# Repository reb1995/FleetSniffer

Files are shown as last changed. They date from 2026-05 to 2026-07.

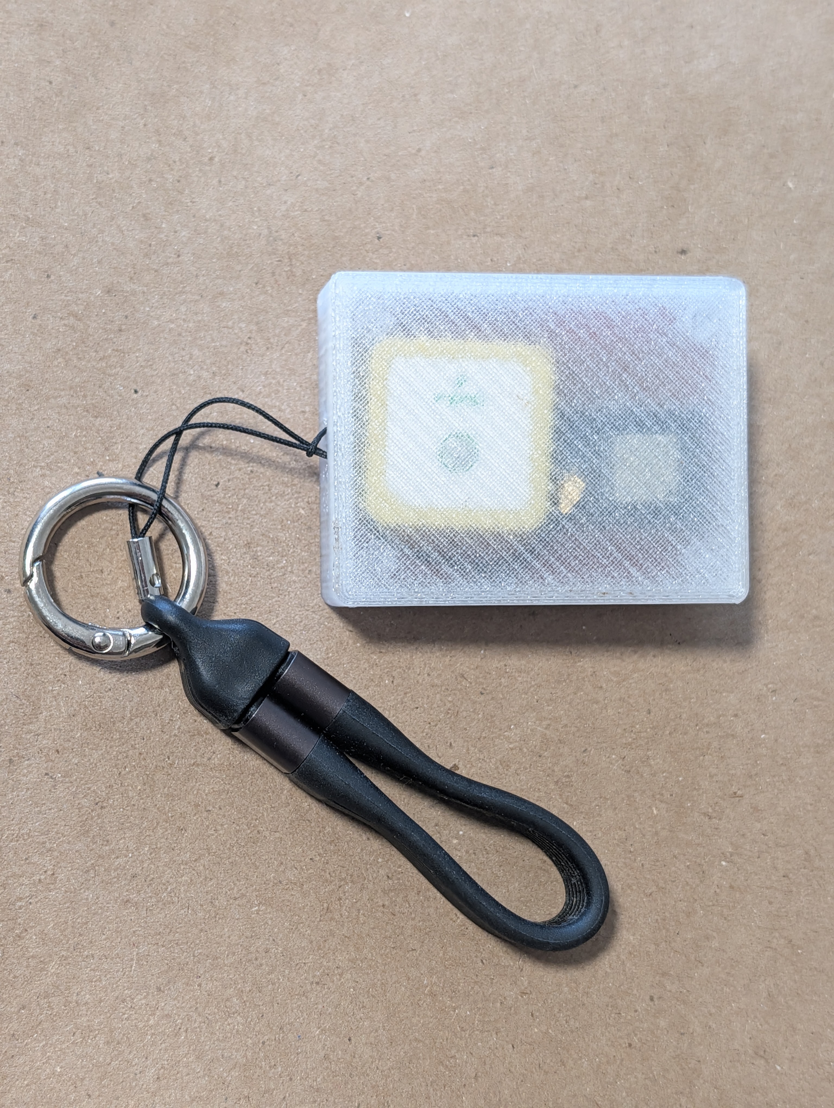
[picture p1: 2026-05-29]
models/images/Bottom.jpg

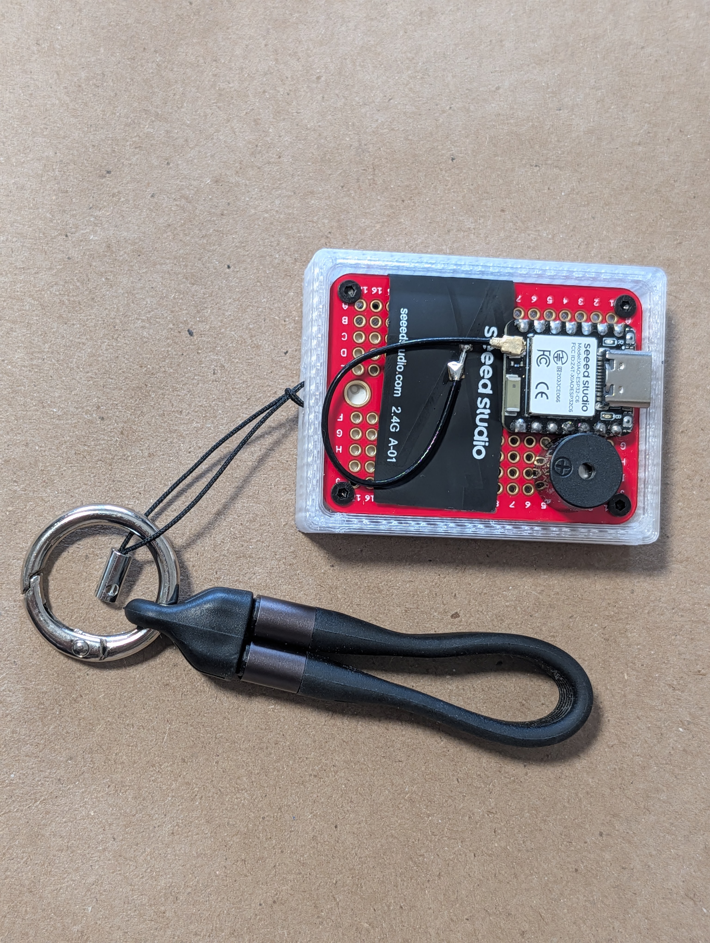
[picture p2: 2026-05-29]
models/images/Top.jpg

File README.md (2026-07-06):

ESP32 Passive Network Monitor
=============================
Pre-Release
------------------
This is a working project, but it is not refined. Some assembly required. For example, the 3d printed case doesn't fit the buzzer and doesn't have a shield to protect the front of the case. Feel free to update and optimize.

Design
------------------

Multi-protocol network monitoring tool built on the ESP-IDF. This firmware passively scans for 802.11 management frames (Beacons, Probe Requests, Probe Responses) and Bluetooth Low Energy (BLE) advertisements. It cross-references captured MAC addresses, OUIs, and SSIDs against embedded watchlists, triggers GPIO alerts upon detection, and logs matched targets to non-volatile SPIFFS memory.

Supported Hardware
------------------

This project leverages static DRAM allocation and IRAM-pinned interrupt callbacks to handle high-density RF environments without dropping packets. It is explicitly designed to compile across multiple ESP32 architectures:

*   **ESP32-C5:** Supports dual-band channel hopping (2.4 GHz & 5 GHz).
    *   Hardware pins:
        *   Buzzer (GPIO 9)
        *   LED (GPIO 27)
*   **ESP32-C6:** High-efficiency 2.4 GHz monitoring.
    *   Hardware pins:
        *   Buzzer (GPIO 20)
        *   LED (GPIO 15)
*   **ESP32-S3:** 2.4 GHz monitoring.
    *   Hardware pins:
        *   Buzzer (GPIO 8)
        *   LED (GPIO 21)

Compile for your specific hardware. The C5 build automatically includes 5 GHz channel sweeping logic.

``` bash
idf.py set-target esp32x#
```

Watchlists and Configuration
----------------------------

The system uses hardcoded static arrays to identify targets of interest. This is highly effective for auditing specific infrastructure, verifying authorized broadcasts, or tracking fleet vehicles equipped with distinct mobile routers.

These arrays have basic targets and ignore lists. You will need to update these for your specific area. Review alerts, determine false positives, and update accordingly. Update these arrays in main.c to fit your operational requirements:

*   **target\_ouis**: Matches the first 3 bytes of a MAC address to identify specific hardware vendors.
*   **target\_ssids**: Substring matching for Wi-Fi network names.
*   **target\_ble\_names**: Substring matching for BLE advertisement names.
*   **ignore\_ssids**: Blacklist arrays to filter out false positives (e.g., expected ambient networks).

SPIFFS Target Logging
---------------------

When a device matches your watchlist, the alert task activates the GPIO buzzer/LED and permanently logs the target to the onboard flash memory (/spiffs/targets.txt). This ensures data survives reboots or power loss during field operations.

The system reads this log on boot and outputs it to the console. The log file is formatted as follows:

``` bash
MAC Address       | Total | P-Req | P-Rsp | Beacons | RSSI | Chan | SSID | Vendor
xx:xx:xx:xx:xx:xx | 3     | 0     | 0     | 3       | -48  | 1    | Network | MegaVendor | [YYYY-MM-DD 20:10:00] | 38.89555, -77.02519
xx:xx:xx:xx:xx:xx | 3     | 0     | 0     | 3       | -59  | 40   | Network Guest | MegaVendor | [YYYY-MM-DD 20:10:00] | 38.89555, -77.02519
```

GPS Tracking
---------------------

When a Seeed Studios L76K GPS antenna is installed to the scanner, it will automatically detect GPS and append date and GPS coordinates to logged detections. If there is no GPS, the program will continue without date or location tracking.

Live Terminal Output
--------------------

The console refreshes every 5 seconds, providing a real-time, sorted view of the surrounding RF environment. Devices that match triggering conditions appear at the top. Devices are cleared from the live view after 30 seconds of inactivity to maintain a clean, active operational picture.

Build Instructions
------------------

1.  Initialize the environment.
2.  Set your target chip: esp32c5, c6, or s3.
3.  Build the project.
4.  Flash and monitor.

``` bash
. ./esp-idf-v5.5.4/export.sh
idf.py set-target esp32c5
idf.py build
idf.py flash monitor
```

Materials
------------------

1.  **Seeed Studios Xiao**: https://www.seeedstudio.com/Seeed-Studio-XIAO-c-2428.html
3.  **Seeed Studios Xiao GPS**: https://www.seeedstudio.com/L76K-GNSS-Module-for-Seeed-Studio-XIAO-p-5864.html
3.  **ElectroCookie Mini PCB**: https://www.amazon.com/dp/B081MSKJJX
4.  **3V Active Buzzer**: https://www.amazon.com/dp/B07VRK7ZPF
4.  **2mm Screws**: https://www.amazon.com/dp/B0CQP76MD8

Assembly
------------------

1. Solder female headers onto the L76K GPS board.
2. Make sure Xiao board is fully seated into the proto board.
2. Solder at least the GND and D9 pins on the Xiao to the protoboard at F2 and F5.
3. Solder the positive leg of the beeper to I5 and negative to I2.
4. Seat L76K board female pints to Xiao board male pins.
5. Wrap GPS antenna wire around antenna and neatly tuck it under proto board, I promise it fits.
6. Screw 4x 2mm screws through proto board corners to lock into base.
7. Redesign top to actually fit buzzer and USB Cables or print top as is and use a dremel and a dream to make it fit.

Mapping Targets
------------------

If using a GPS, you can map the hits later. In the map folder, there is a demo log and python script to generate an index.html file that will map the hits on OpenStreetMap.

``` bash
python3 -m venv env
. env/bin/activate
pip install -r requirements.txt
python map_generator.py demo_log.txt
```

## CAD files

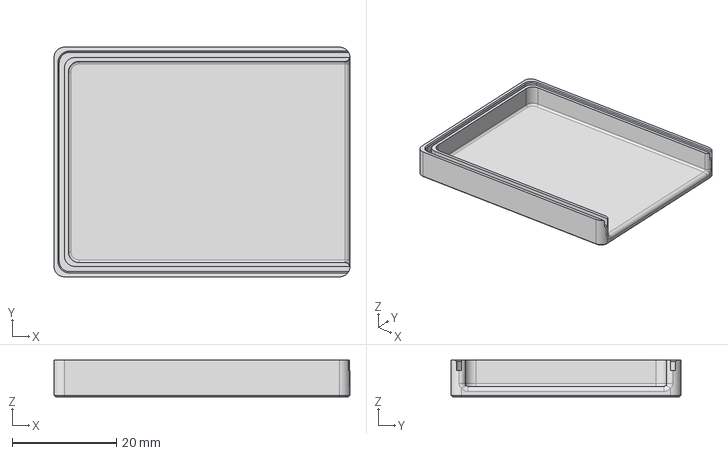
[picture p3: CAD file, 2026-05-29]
models/step/FleetSniffer Top.step
56.7 x 44.0 x 7.00 mm

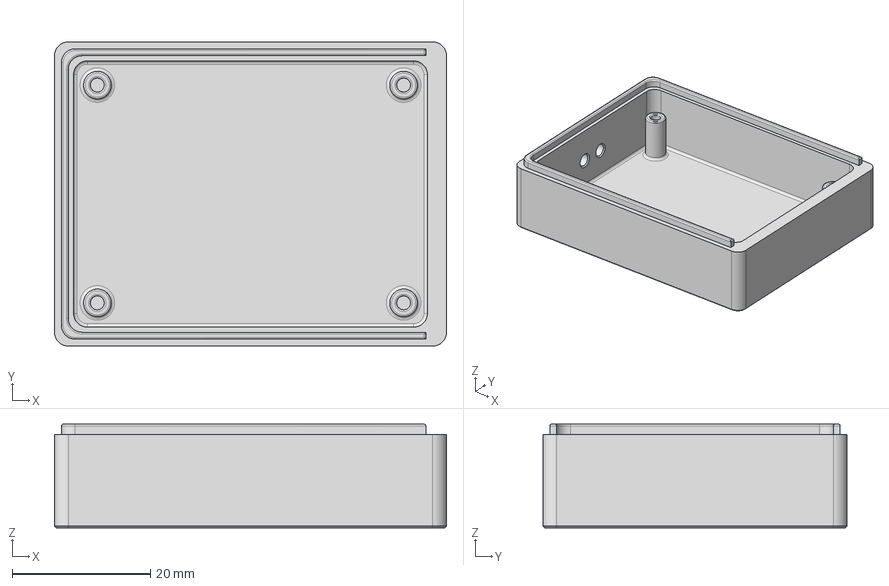
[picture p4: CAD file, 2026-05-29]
models/step/FleetSniffer Body.step
56.7 x 44.0 x 15.0 mm

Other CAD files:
models/stl/FleetSniffer Body.stl
models/stl/FleetSniffer Top.stl

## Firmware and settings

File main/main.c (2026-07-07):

#include <stdio.h>
#include <string.h>
#include <strings.h>
#include "freertos/FreeRTOS.h"
#include "freertos/task.h"
#include "freertos/semphr.h"
#include "esp_system.h"
#include "esp_wifi.h"
#include "esp_event.h"
#include "esp_log.h"
#include "nvs_flash.h"
#include "esp_netif.h"
#include "esp_heap_caps.h"
#include "driver/gpio.h"
#include "esp_task_wdt.h"
#include "soc/soc_caps.h"

// GPS
#include "driver/uart.h"
#define UART_PORT UART_NUM_1
#define BAUD_RATE 9600

// NimBLE
#include "nimble/nimble_port.h"
#include "nimble/nimble_port_freertos.h"
#include "host/ble_hs.h"
#include "host/util/util.h"

// SPIFFS
#include "esp_spiffs.h"
#include <sys/time.h>
#include <sys/stat.h>

// Screen
#include "driver/i2c.h"

//#define PRINT_INTERVAL_MS 5000
#define PRINT_INTERVAL_START_MS 2000
#define PRINT_INTERVAL_END_MS 2000
#define DEVICE_TIMEOUT_MS 10000

#define I2C_MASTER_NUM  0
#define I2C_MASTER_FREQ_HZ 400000
#define OLED_ADDR 0x3C

static bool has_screen = false;
static SemaphoreHandle_t oled_mutex;

static char oled_line1[38] = "WAITING FOR";
static char oled_line2[38] = "TARGET";
static char oled_line3[38] = "";

#ifdef CONFIG_IDF_TARGET_ESP32C5
    #define BUZZER_PIN 9 // D9
    #define LED_PIN 27 // built in
    #define TX_PIN 11 // D6
    #define RX_PIN 12 // D7
    #define I2C_MASTER_SDA_IO 23
    #define I2C_MASTER_SCL_IO 24
#endif

#ifdef CONFIG_IDF_TARGET_ESP32C6
    #define BUZZER_PIN 20 // D9
    #define LED_PIN 15 //built in
    #define TX_PIN 16 // D6
    #define RX_PIN 17 // D7
    #define RF_SW_PWR_PIN 3    // Power for RF Switch
    #define RF_ANT_SEL_PIN 14  // External Antenna Select
    #define I2C_MASTER_SDA_IO 22
    #define I2C_MASTER_SCL_IO 23
#endif

#ifdef CONFIG_IDF_TARGET_ESP32S3
    #define BUZZER_PIN 1 // D9
    #define LED_PIN 21 // built in
    #define TX_PIN 43 // D6
    #define RX_PIN 44 // D7
    #define I2C_MASTER_SDA_IO 5
    #define I2C_MASTER_SCL_IO 6
#endif

#define MAX_DEVICES 512

#define MEM_CAPS (MALLOC_CAP_INTERNAL | MALLOC_CAP_8BIT)

// --- ALERT TARGETS ---
typedef struct {
    uint8_t oui[3];
    const char *description;
} target_oui_t;

static DRAM_ATTR const char *target_ble_names[] = {
    "AXON"
};

static DRAM_ATTR const char *target_ssids[] = {
//    ".", // Test SSID
    "Fire", // Generic
    "EMS", // Generic
    "Police", // Generic
    "Axon" // Generic
};

static DRAM_ATTR const target_oui_t target_ouis[] = {
//    { {0x02, 0x00, 0x00}, "Test OUI" }, // Private LAA. Should never actually see this OUI. But you do, apparently.
    { {0x00, 0x58, 0x28}, "AXON" }, // Axon.
    { {0x00, 0xC0, 0xD4}, "AXON" }, // Axon
    { {0x84, 0x70, 0x03}, "AXON" }, // Axon
    { {0x00, 0x25, 0xDF}, "AXON Enterprise" }, // Axon Enterprise. Probably only cops.
    { {0x00, 0x11, 0x6E}, "Peplink" }, // Peplink
    { {0x10, 0x56, 0xCA}, "Peplink" }, // Peplink
    { {0xd4, 0x13, 0xF7}, "Peplink" }, // Peplink
    { {0x28, 0xEA, 0x5B}, "Samsara" }, // Samsara Networks INC
    { {0xC0, 0xD3, 0x91}, "Samsara" }, // Samsara Networks INC. Only /28 so false positives.
    { {0x00, 0x1C, 0x04}, "Airgain" }, // Airgain INC
    { {0xB8, 0x4C, 0x87}, "Airgain" }, // Airgain INC
    { {0x00, 0x40, 0x02}, "Perle Systems" }, // Perle Systems
    { {0x00, 0x14, 0x3E}, "AirLink" }, //
    { {0x28, 0xA3, 0x31}, "Sierra Wireless" }, //
    { {0x00, 0x30, 0x44}, "CradlePoint" }, //
    { {0x00, 0xE0, 0x1C}, "CradlePoint" }, //
    { {0xE8, 0x4E, 0x06}, "EDUP" }, // Dashcams
    { {0x34, 0x8A, 0x12}, "HPE" },
    { {0xCC, 0x78, 0xAB}, "Zebra Printer" }, // Mobile ticket printers
    { {0xAC, 0x4D, 0x16}, "Zebra Printer" }, // Mobile ticket printers
    { {0xC4, 0xD3, 0x6A}, "Zebra Printer" } // Mobile ticket printers
};

// Mostly SSIDs but could also be bluetooth names.
static DRAM_ATTR const char *ignore_names[] = {
    "problems", // FP protection. Stops common EMS false positive
    "systems", // FP protection. Stops common EMS false positive
    "not in use", // Mostly Raleigh Buses
    "Public WiFi", // FP. Public WiFi probably isn't a hit...
    "Public-WiFi", // FP. Public WiFi probably isn't a hit...
    "Bus", // FP.
    "CTFCU", // Local business: "Carolinas Telco Federal Credit Union"
    "ALLSystemsGo", // FP.
    "RAI-SIGNAGE", // FP. CradlePoint
    "IKE Free Wifi", // FP. Raleigh Interactive Kiosks. Cradlepoint
    "AMRED", // FP. American Red Cross. Cradlepoint
    "LFwireless" // FP. Life Fitness default SSID. EDUP.
    "WHUIS", // FP. Waffle House?
    "ecoATM", // FP.
    "PrePass", // FP.
    "SaleemsFamily", // FP.
    "SprinterWiFi", // FP.
    "IncidentClear", // FP.
    "H&R Block", // FP.
    "Health Team", // FP.
    "Tunnel Hill", // FP.
    "PureTech", // FP.
    "NiFleet", // FP.
    "Penske", // FP.
    "Tesla", // FP.
    "Drivewyze", // FP.
    "CIS-RX", // FP.
    "GoEnergy", // FP.
    "AVIT", // FP.
    "JimmyJohns", // FP.
    "Transit", // FP.
    "Rivian" // FP.
};

const int num_target_ssids = sizeof(target_ssids) / sizeof(target_ssids[0]);
const int num_target_ble_names = sizeof(target_ble_names) / sizeof(target_ble_names[0]);
const int num_target_ouis = sizeof(target_ouis) / sizeof(target_ouis[0]);
const int num_ignore_names = sizeof(ignore_names) / sizeof(ignore_names[0]);

static char gps_date_str[16] = {0};
static char gps_time_str[16] = {0};
static char gps_lat_str[16] = {0};
static char gps_lon_str[16] = {0};
static int gps_satellites_tracked = 0;
static int temp_sats_in_view = 0;
static bool gps_valid = false;
static volatile bool gps_hardware_detected = false;

static SemaphoreHandle_t data_mutex;

// ---------------------
// OLED Functions
static const uint8_t font5x8[96][5] = {
    {0x00,0x00,0x00,0x00,0x00},{0x00,0x00,0x5F,0x00,0x00},{0x00,0x07,0x00,0x07,0x00},{0x14,0x7F,0x14,0x7F,0x14},
    {0x24,0x2A,0x7F,0x2A,0x12},{0x23,0x13,0x08,0x64,0x62},{0x36,0x49,0x55,0x22,0x50},{0x00,0x05,0x03,0x00,0x00},
    {0x00,0x1C,0x22,0x41,0x00},{0x00,0x41,0x22,0x1C,0x00},{0x08,0x2A,0x1C,0x2A,0x08},{0x08,0x08,0x3E,0x08,0x08},
    {0x00,0x50,0x30,0x00,0x00},{0x08,0x08,0x08,0x08,0x08},{0x00,0x60,0x60,0x00,0x00},{0x20,0x10,0x08,0x04,0x02},
    {0x3E,0x51,0x49,0x45,0x3E},{0x00,0x42,0x7F,0x40,0x00},{0x42,0x61,0x51,0x49,0x46},{0x21,0x41,0x45,0x4B,0x31},
    {0x18,0x14,0x12,0x7F,0x10},{0x27,0x45,0x45,0x45,0x39},{0x3C,0x4A,0x49,0x49,0x30},{0x01,0x71,0x09,0x05,0x03},
    {0x36,0x49,0x49,0x49,0x36},{0x06,0x49,0x49,0x29,0x1E},{0x00,0x36,0x36,0x00,0x00},{0x00,0x56,0x36,0x00,0x00},
    {0x00,0x08,0x14,0x22,0x41},{0x14,0x14,0x14,0x14,0x14},{0x41,0x22,0x14,0x08,0x00},{0x02,0x01,0x51,0x09,0x06},
    {0x32,0x49,0x79,0x41,0x3E},{0x7E,0x11,0x11,0x11,0x7E},{0x7F,0x49,0x49,0x49,0x36},{0x3E,0x41,0x41,0x41,0x22},
    {0x7F,0x41,0x41,0x22,0x1C},{0x7F,0x49,0x49,0x49,0x41},{0x7F,0x09,0x09,0x01,0x01},{0x3E,0x41,0x41,0x51,0x32},
    {0x7F,0x08,0x08,0x08,0x7F},{0x00,0x41,0x7F,0x41,0x00},{0x20,0x40,0x41,0x3F,0x01},{0x7F,0x08,0x14,0x22,0x41},
    {0x7F,0x40,0x40,0x40,0x40},{0x7F,0x02,0x04,0x02,0x7F},{0x7F,0x04,0x08,0x10,0x7F},{0x3E,0x41,0x41,0x41,0x3E},
    {0x7F,0x09,0x09,0x09,0x06},{0x3E,0x41,0x51,0x21,0x5E},{0x7F,0x09,0x19,0x29,0x46},{0x46,0x49,0x49,0x49,0x31},
    {0x01,0x01,0x7F,0x01,0x01},{0x3F,0x40,0x40,0x40,0x3F},{0x1F,0x20,0x40,0x20,0x1F},{0x7F,0x20,0x18,0x20,0x7F},
    {0x63,0x14,0x08,0x14,0x63},{0x03,0x04,0x78,0x04,0x03},{0x61,0x51,0x49,0x45,0x43},{0x00,0x00,0x7F,0x41,0x41},
    {0x02,0x04,0x08,0x10,0x20},{0x41,0x41,0x7F,0x00,0x00},{0x04,0x02,0x01,0x02,0x04},{0x40,0x40,0x40,0x40,0x40},
    {0x00,0x01,0x02,0x04,0x00},{0x20,0x54,0x54,0x54,0x78},{0x7F,0x48,0x44,0x44,0x38},{0x38,0x44,0x44,0x44,0x20},
    {0x38,0x44,0x44,0x48,0x7F},{0x38,0x54,0x54,0x54,0x18},{0x08,0x7E,0x09,0x01,0x02},{0x08,0x14,0x54,0x54,0x3C},
    {0x7F,0x08,0x04,0x04,0x78},{0x00,0x44,0x7D,0x40,0x00},{0x20,0x40,0x44,0x3D,0x00},{0x00,0x7F,0x10,0x28,0x44},
    {0x00,0x41,0x7F,0x40,0x00},{0x7C,0x04,0x18,0x04,0x78},{0x7C,0x08,0x04,0x04,0x78},{0x38,0x44,0x44,0x44,0x38},
    {0x7C,0x14,0x14,0x14,0x08},{0x08,0x14,0x14,0x18,0x7C},{0x7C,0x08,0x04,0x04,0x08},{0x48,0x54,0x54,0x54,0x20},
    {0x04,0x3F,0x44,0x40,0x20},{0x3C,0x40,0x40,0x20,0x7C},{0x1C,0x20,0x40,0x20,0x1C},{0x3C,0x40,0x30,0x40,0x3C},
    {0x44,0x28,0x10,0x28,0x44},{0x0C,0x50,0x50,0x50,0x3C},{0x44,0x64,0x54,0x4C,0x44},{0x00,0x08,0x36,0x41,0x00},
    {0x00,0x00,0x7F,0x00,0x00},{0x00,0x41,0x36,0x08,0x00},{0x08,0x04,0x08,0x10,0x08},{0x00,0x00,0x00,0x00,0x00}
};

static void oled_cmd(uint8_t cmd) {
    if(!has_screen) return;
    uint8_t data[2] = {0x00, cmd};
    i2c_master_write_to_device(I2C_MASTER_NUM, OLED_ADDR, data, 2, pdMS_TO_TICKS(100));
}

static void ssd1306_clear(void) {
    if(!has_screen) return;
    uint8_t data[129];
    data[0] = 0x40;
    memset(&data[1], 0x00, 128);
    for (uint8_t page = 0; page < 8; page++) {
        oled_cmd(0xB0 + page); oled_cmd(0x00); oled_cmd(0x10);
        i2c_master_write_to_device(I2C_MASTER_NUM, OLED_ADDR, data, 129, pdMS_TO_TICKS(100));
    }
}

static void ssd1306_print_line_2x(uint8_t page, const char* str, bool invert) {
    if(!has_screen || !str) return;

    uint8_t data_top[129];
    uint8_t data_bot[129];
    data_top[0] = 0x40;
    data_bot[0] = 0x40;
    memset(&data_top[1], invert ? 0xFF : 0x00, 128);
    memset(&data_bot[1], invert ? 0xFF : 0x00, 128);

    int len = strlen(str);
    if (len > 21) len = 21;

    int start_x = (128 - (len * 6)) / 2; // Center alignment
    int idx = 1 + start_x;

    for (int i = 0; i < len; i++) {
        char c = str[i];
        if (c < 32 || c > 127) c = '?';
        for (int col = 0; col < 5; col++) {
            uint8_t b = font5x8[c - 32][col];
            if (invert) b = ~b;

            // Stretch bits vertically
            uint8_t top = 0, bot = 0;
            for (int bit = 0; bit < 4; bit++) {
                if (b & (1 << bit)) top |= (3 << (bit * 2));
                if (b & (1 << (bit + 4))) bot |= (3 << (bit * 2));
            }
            data_top[idx] = top;
            data_bot[idx] = bot;
            idx++;
        }
        data_top[idx] = invert ? 0xFF : 0x00;
        data_bot[idx] = invert ? 0xFF : 0x00;
        idx++;
    }

    uint8_t cmds_top[4] = {0x00, 0xB0 + page, 0x00, 0x10};
    i2c_master_write_to_device(I2C_MASTER_NUM, OLED_ADDR, cmds_top, 4, pdMS_TO_TICKS(100));
    i2c_master_write_to_device(I2C_MASTER_NUM, OLED_ADDR, data_top, 129, pdMS_TO_TICKS(100));

    uint8_t cmds_bot[4] = {0x00, 0xB0 + page + 1, 0x00, 0x10};
    i2c_master_write_to_device(I2C_MASTER_NUM, OLED_ADDR, cmds_bot, 4, pdMS_TO_TICKS(100));
    i2c_master_write_to_device(I2C_MASTER_NUM, OLED_ADDR, data_bot, 129, pdMS_TO_TICKS(100));
}

static void init_oled(void) {
    i2c_config_t conf = {
        .mode = I2C_MODE_MASTER,
        .sda_io_num = I2C_MASTER_SDA_IO,
        .scl_io_num = I2C_MASTER_SCL_IO,
        .sda_pullup_en = GPIO_PULLUP_ENABLE,
        .scl_pullup_en = GPIO_PULLUP_ENABLE,
        .master.clk_speed = I2C_MASTER_FREQ_HZ,
    };
    i2c_param_config(I2C_MASTER_NUM, &conf);
    i2c_driver_install(I2C_MASTER_NUM, conf.mode, 0, 0, 0);

    i2c_cmd_handle_t cmd = i2c_cmd_link_create();
    i2c_master_start(cmd);
    i2c_master_write_byte(cmd, (OLED_ADDR << 1) | I2C_MASTER_WRITE, true);
    i2c_master_stop(cmd);
    esp_err_t ret = i2c_master_cmd_begin(I2C_MASTER_NUM, cmd, pdMS_TO_TICKS(100));
    i2c_cmd_link_delete(cmd);

    if (ret == ESP_OK) {
        has_screen = true;
        uint8_t init_cmds[] = {
            0xAE, 0xD5, 0x80, 0xA8, 0x3F, 0xD3, 0x00, 0x40,
            0x8D, 0x14, 0x20, 0x02, 0xA1, 0xC8, 0xDA, 0x12,
            0x81, 0xFF, 0xD9, 0xF1, 0xDB, 0x40, 0xA4, 0xA6, 0xAF
        };
        for(int i=0; i<sizeof(init_cmds); i++) oled_cmd(init_cmds[i]);
        ssd1306_clear();
    }
}

void oled_task(void *pvParameters) {
    while (1) {
        if (has_screen) {
            if (xSemaphoreTake(oled_mutex, portMAX_DELAY)) {
                ssd1306_print_line_2x(0, oled_line1, false);
                ssd1306_print_line_2x(3, oled_line2, false);
                ssd1306_print_line_2x(6, oled_line3, false);
                xSemaphoreGive(oled_mutex);
            }
        }
        vTaskDelay(pdMS_TO_TICKS(1000));
    }
}

// OLED Functions
// ---------------------

static TaskHandle_t alert_task_handle = NULL;

typedef enum { PROTO_WIFI, PROTO_BLE } protocol_t;

typedef struct {
    uint8_t mac[6];
    protocol_t protocol;
    uint32_t packet_count;
    uint32_t probe_req_count;
    uint32_t probe_resp_count;
    uint32_t beacon_count;
    int8_t strongest_rssi;
    uint8_t channel;
    bool active;
    char name_ssid[33];
    uint32_t last_seen_timestamp;
    bool is_target;
    bool logged;
} device_stat_t;

// Force these arrays into internal Data RAM (DRAM)
static DRAM_ATTR device_stat_t wifi_devices_static[MAX_DEVICES];
static DRAM_ATTR device_stat_t ble_devices_static[MAX_DEVICES];

// Pointers that the rest of the code uses to access that static memory
static device_stat_t *wifi_devices = wifi_devices_static;
static device_stat_t *ble_devices = ble_devices_static;

void print_text_log_to_console() {
    FILE* f = fopen("/spiffs/targets.txt", "r");
    if (f == NULL) {
        printf("--- No Target Log Found ---\n");
        return;
    }
    printf("\n--- SAVED TARGETS ---\n");
    printf("MAC Address       | Total | P-Req | P-Rsp | Beacons | RSSI | Chan | SSID | Vendor \n");

    char line[128];
    while (fgets(line, sizeof(line), f) != NULL) {
        printf("%s", line);
        vTaskDelay(1);
    }
    printf("---------------------\n\n");
    fclose(f);
}

void append_target_to_file(device_stat_t *dev) {
    FILE* f = fopen("/spiffs/targets.txt", "a");
    if (f == NULL) return;

    const char *vendor = "Unknown";
    if ((dev->mac[1] == 0x30 && dev->mac[2] == 0x44) || (dev->mac[1] == 0xE0 && dev->mac[2] == 0x1C)) {
        vendor = "CradlePoint vMAC";
    } else if (dev->mac[1] == 0xA3 && dev->mac[2] == 0x31) {
        vendor = "Sierra W vMAC";
    } else if (dev->mac[1] == 0x14 && dev->mac[2] == 0x3E) {
        vendor = "AirLink vMAC";
    } else {
        for(int j=0; j<num_target_ouis; j++) {
            if(memcmp(dev->mac, target_ouis[j].oui, 3) == 0) {
                vendor = target_ouis[j].description;
                break;
            }
        }
    }

    if (gps_valid) {
        fprintf(f, "%02x:%02x:%02x:%02x:%02x:%02x | %-5lu | %-5lu | %-5lu | %-7lu | %-4d | %-4u | %s | %s | [%s %s] | %s, %s\n",
                dev->mac[0], dev->mac[1], dev->mac[2], dev->mac[3], dev->mac[4], dev->mac[5],
                dev->packet_count, dev->probe_req_count, dev->probe_resp_count, dev->beacon_count,
                dev->strongest_rssi, dev->channel, dev->name_ssid[0] ? dev->name_ssid : "<hidden>", vendor,
                gps_date_str, gps_time_str, gps_lat_str, gps_lon_str);
    } else {
        fprintf(f, "%02x:%02x:%02x:%02x:%02x:%02x | %-5lu | %-5lu | %-5lu | %-7lu | %-4d | %-4u | %s | %s\n",
                dev->mac[0], dev->mac[1], dev->mac[2], dev->mac[3], dev->mac[4], dev->mac[5],
                dev->packet_count, dev->probe_req_count, dev->probe_resp_count, dev->beacon_count,
                dev->strongest_rssi, dev->channel, dev->name_ssid[0] ? dev->name_ssid : "<hidden>", vendor);
    }
    fclose(f);
}

static uint32_t IRAM_ATTR hash_mac(const uint8_t *mac) {
    uint32_t hash = 5381;
    for (int i = 0; i < 6; i++) {
        hash = ((hash << 5) + hash) + mac[i];
    }
    return hash % MAX_DEVICES;
}

int compare_devices(const void *a, const void *b) {
    device_stat_t *devA = (device_stat_t *)a;
    device_stat_t *devB = (device_stat_t *)b;
    if (devA->is_target && !devB->is_target) return -1;
    if (!devA->is_target && devB->is_target) return 1;
    return (devB->strongest_rssi - devA->strongest_rssi);
}

static void IRAM_ATTR update_device_record(device_stat_t *list, const uint8_t *mac, protocol_t proto, int8_t rssi, uint8_t channel, uint8_t subtype, const char *name, bool is_target) {
    if (xSemaphoreTake(data_mutex, 0) == pdTRUE) {
        uint32_t start_idx = hash_mac(mac);
        uint32_t idx = start_idx;

        for (int i = 0; i < MAX_DEVICES; i++) {
            if (!list[idx].active) {
                memcpy(list[idx].mac, mac, 6);
                list[idx].protocol = proto;
                list[idx].packet_count = 1;
                list[idx].strongest_rssi = rssi;
                list[idx].channel = channel;
                list[idx].active = true;
                list[idx].is_target = is_target;

                if (proto == PROTO_WIFI) {
                    if (subtype == 4) list[idx].probe_req_count = 1;
                    else if (subtype == 5) list[idx].probe_resp_count = 1;
                    else if (subtype == 8) list[idx].beacon_count = 1;
                }

                if (name && name[0] != '\0') {
                    strlcpy(list[idx].name_ssid, name, sizeof(list[idx].name_ssid));
                }

                list[idx].last_seen_timestamp = xTaskGetTickCount();
                break;
            } else if (memcmp(list[idx].mac, mac, 6) == 0) {
                list[idx].packet_count++;
                if (is_target) {
                    if ((name && name[0] != '\0') || list[idx].name_ssid[0] == '\0') {
                        list[idx].is_target = true;
                    }
                }
                if (proto == PROTO_WIFI) {
                    if (subtype == 4) list[idx].probe_req_count++;
                    else if (subtype == 5) list[idx].probe_resp_count++;
                    else if (subtype == 8) list[idx].beacon_count++;
                }
                if (rssi > list[idx].strongest_rssi) {
                    list[idx].strongest_rssi = rssi;
                    list[idx].channel = channel;
                }
                if (name && name[0] != '\0') {
                    strlcpy(list[idx].name_ssid, name, sizeof(list[idx].name_ssid));
                }
                list[idx].last_seen_timestamp = xTaskGetTickCount();
                break;
            }
            idx = (idx + 1) % MAX_DEVICES;
        }
        xSemaphoreGive(data_mutex);
    }
}
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
void app_main(void) {
    ESP_ERROR_CHECK(nvs_flash_init());

    esp_vfs_spiffs_conf_t conf = { .base_path = "/spiffs", .partition_label = NULL, .max_files = 5, .format_if_mount_failed = true };
    esp_vfs_spiffs_register(&conf);

    // Clear logged targets on boot
    //remove("/spiffs/targets.txt");

    print_text_log_to_console();

    ESP_ERROR_CHECK(esp_netif_init());
    ESP_ERROR_CHECK(esp_event_loop_create_default());

    xTaskCreate(alert_task, "alert_task", 2048, NULL, 10, &alert_task_handle);

    data_mutex = xSemaphoreCreateMutex();


#ifdef CONFIG_IDF_TARGET_ESP32C6
    // Seeed XIAO ESP32-C6: Route RF to the external U.FL connector
    gpio_reset_pin(RF_SW_PWR_PIN);
    gpio_set_direction(RF_SW_PWR_PIN, GPIO_MODE_OUTPUT);
    gpio_set_level(RF_SW_PWR_PIN, 0); // LOW = Power ON the RF switch

    // Allow RF switch voltage to stabilize
    vTaskDelay(pdMS_TO_TICKS(100));

    gpio_reset_pin(RF_ANT_SEL_PIN);
    gpio_set_direction(RF_ANT_SEL_PIN, GPIO_MODE_OUTPUT);
    gpio_set_level(RF_ANT_SEL_PIN, 1); // HIGH = Select External Antenna
#endif

    esp_log_level_set("wifi", ESP_LOG_WARN);
    wifi_init_config_t cfg = WIFI_INIT_CONFIG_DEFAULT();
    ESP_ERROR_CHECK(esp_wifi_init(&cfg));
    ESP_ERROR_CHECK(esp_wifi_set_storage(WIFI_STORAGE_RAM));
    ESP_ERROR_CHECK(esp_wifi_set_mode(WIFI_MODE_NULL));
    ESP_ERROR_CHECK(esp_wifi_start());

    // wifi_promiscuous_filter_t filter = { .filter_mask = WIFI_PROMIS_FILTER_MASK_MGMT };
    wifi_promiscuous_filter_t filter = { .filter_mask = WIFI_PROMIS_FILTER_MASK_MGMT | WIFI_PROMIS_FILTER_MASK_DATA }; // also data
    ESP_ERROR_CHECK(esp_wifi_set_promiscuous_filter(&filter));
    ESP_ERROR_CHECK(esp_wifi_set_promiscuous_rx_cb(wifi_sniffer_cb));
    ESP_ERROR_CHECK(esp_wifi_set_promiscuous(true));

    // Bluetooth init
    ESP_ERROR_CHECK(nimble_port_init());
    ble_hs_cfg.sync_cb = ble_on_sync;
    nimble_port_freertos_init(ble_host_task);

    xTaskCreate(gps_task, "gps_task", 3072, NULL, 5, NULL);
    xTaskCreate(wifi_channel_hopper, "wifi_hop", 1536, NULL, 5, NULL);
    xTaskCreate(monitor_print_task, "printer", 3072, NULL, 4, NULL);

    printf("System Tick Rate: %d Hz\n", configTICK_RATE_HZ);
    printf("Tick Period: %lu ms\n", portTICK_PERIOD_MS);
    printf("Max Devices: %d \n", MAX_DEVICES);

    oled_mutex = xSemaphoreCreateMutex();
    init_oled();
    xTaskCreate(oled_task, "oled_task", 2048, NULL, 3, NULL);

    printf("Checking for GPS hardware...\n");
    for (int i = 0; i < 15; i++) {
        if (gps_hardware_detected) break;
        vTaskDelay(pdMS_TO_TICKS(100));
    }
    if (gps_hardware_detected) {
        printf("--> GPS: FOUND\n");
    } else {
        printf("--> GPS: NOT FOUND\n");
    }
    if (has_screen) {
        printf("--> OLED: FOUND\n");
    } else {
        printf("--> OLED: NOT FOUND\n");
    }

    // Beep on boot to know it booted
    boot_beep(3);
}

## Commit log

2026-05-29 Initial commit.
    [FleetSniffer Body.step, FleetSniffer Body.stl, FleetSniffer Top.step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]
2026-05-29 Add images.
    [FleetSniffer Body.step, FleetSniffer Body.stl, FleetSniffer Top.step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]
